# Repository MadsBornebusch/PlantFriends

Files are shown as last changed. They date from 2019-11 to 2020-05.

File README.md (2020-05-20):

<div align="center">
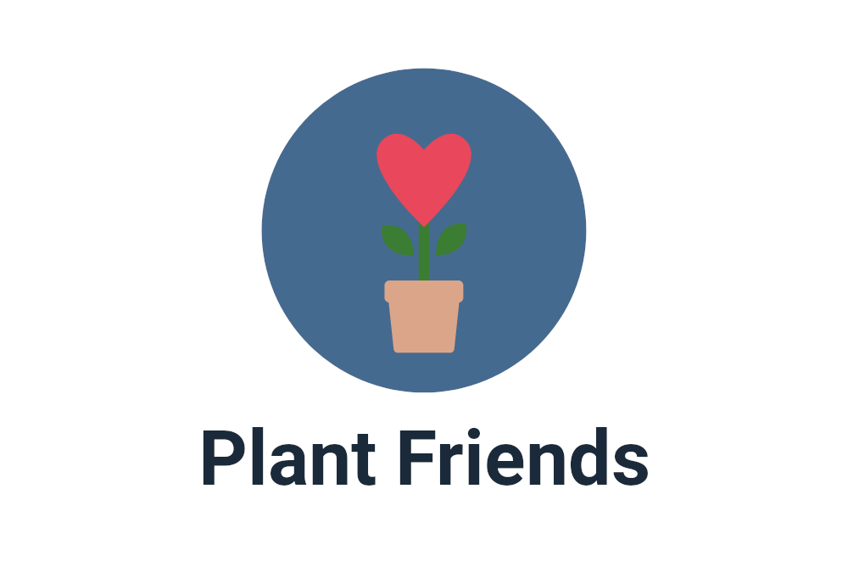
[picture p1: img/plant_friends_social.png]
  
</div>

The code is licensed under the GNU General Public License Version 3.

The PCB is licensed under the Creative Commons Attribution-ShareAlike 4.0 license due to using an [ESP8266 kicad library](https://github.com/jdunmire/kicad-ESP8266) and a particular [soil moisture probe design](https://github.com/acolomitchi/cap-soil-moisture-v2).
_________



This is a plant watering ESP8266.

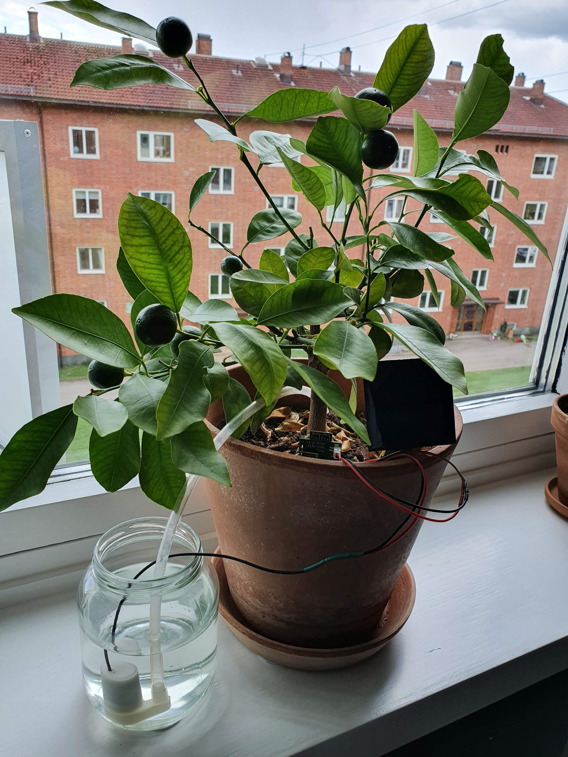
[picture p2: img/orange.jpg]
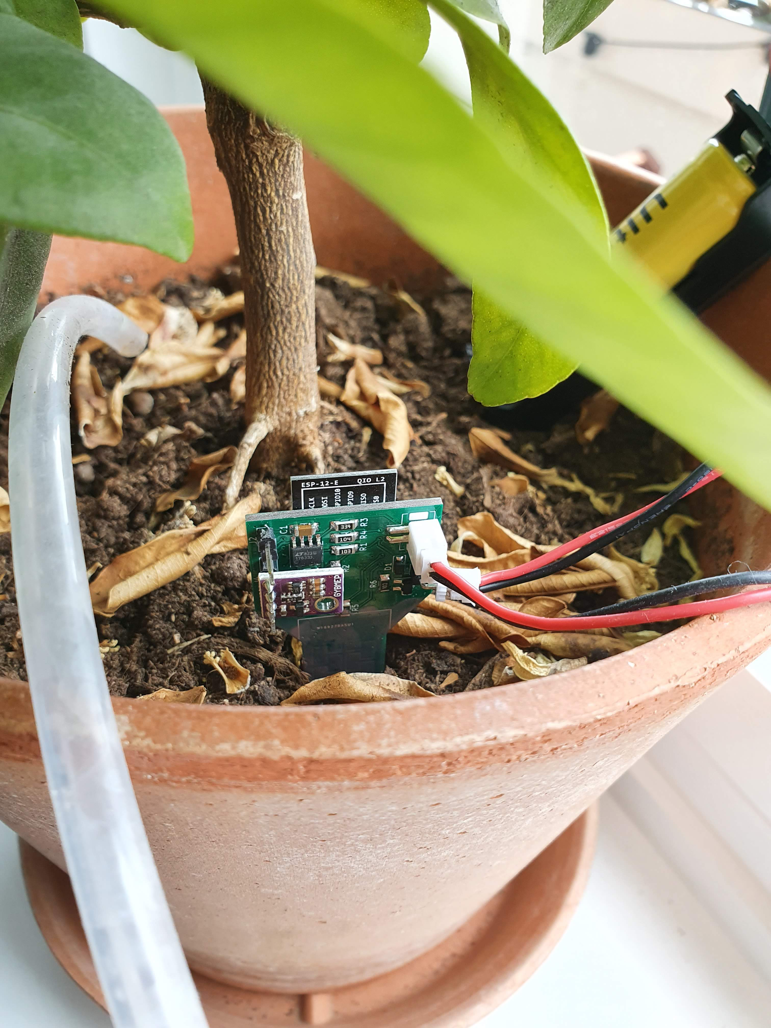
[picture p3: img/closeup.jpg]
 

# Features

* Fully open source (software and hardware)
* Automatic OTA update via Github release - enable/disable using checkbox
* OTA updates via a web interface
* Works with any MQTT server
* Works with Home Assistant discovery
* Set the sleep time, watering delay, water threshold, water time etc via MQTT
* Works with ThingSpeak
* Temperature, pressure and humidity using BME280

# PCB

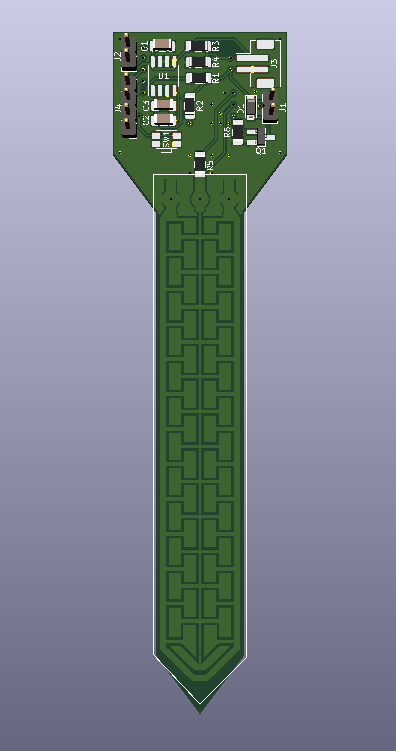
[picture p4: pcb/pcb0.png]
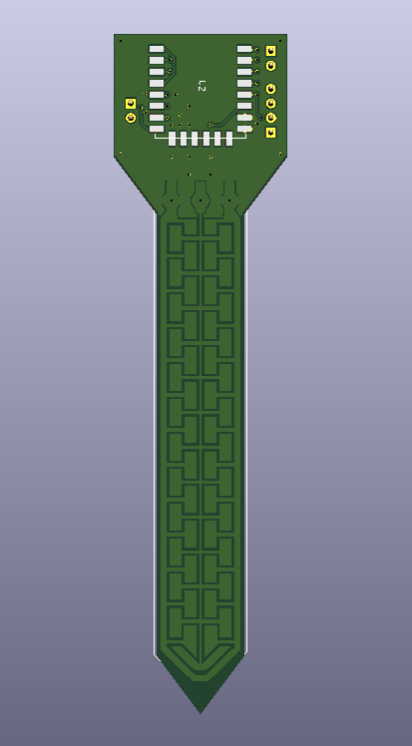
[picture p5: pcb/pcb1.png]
 

## Pinout when seen from component side:

Left side from top:

- FTDI_RX
- FTDI_TX
- SDA
- SCL
- GND
- Battery VCC

## Right side from top:

- Battery VCC IN
- GND
- VCC (3.3 V)
- Watering OUT

# Enclosure

A enclosure meant for 3D printing can be found in the [enclosure](enclosure) directory. Two variant are available. One with a closed top and one with a cutout for mounting a breakout board.

TODO: Add pictures

# Settings

The WiFi, ThingSpeak and MQTT settings can be configured via a web interface:

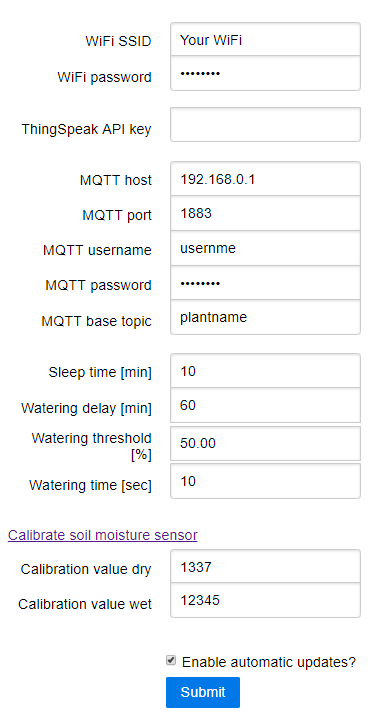
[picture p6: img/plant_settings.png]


If you do not want to use ThingSpeak simply leave the `ThingSpeak API key` field empty. Similarly the MQTT can be disabled by leaving the `MQTT base topic` empty.

At first boot the module will turn on a hotspot with the SSID: `PlantFriends` and password: `plantsarecool`.

After logging on to the WiFI simply navigate to <http://plantfriends.local> or <http://192.168.4.1> to configure the module.

The device can be put back into hotspot mode by shorting the TX and RX pins and restarting the module.

A new firmware and file system image can be uploaded by navigation to <http://plantfriends.local/update> or <http://192.168.4.1/update>.

## Calibrating the soil moisture sensor
Click "Calibrate Soil moisture sensor".
Follow the instructions. Some handy tips:
- Don't get the electronics wet, only the sensor part
- When doing the wet calibration, use a half full glass of water (or half empty if you are that tye of person). Half of the sensor should be in water. Otherwise the readings when the sensor is put in soil will be very low.
- If you need to redo a step in the calibration, just refresh the page.

Images of the wet and dry calibration are shown below:

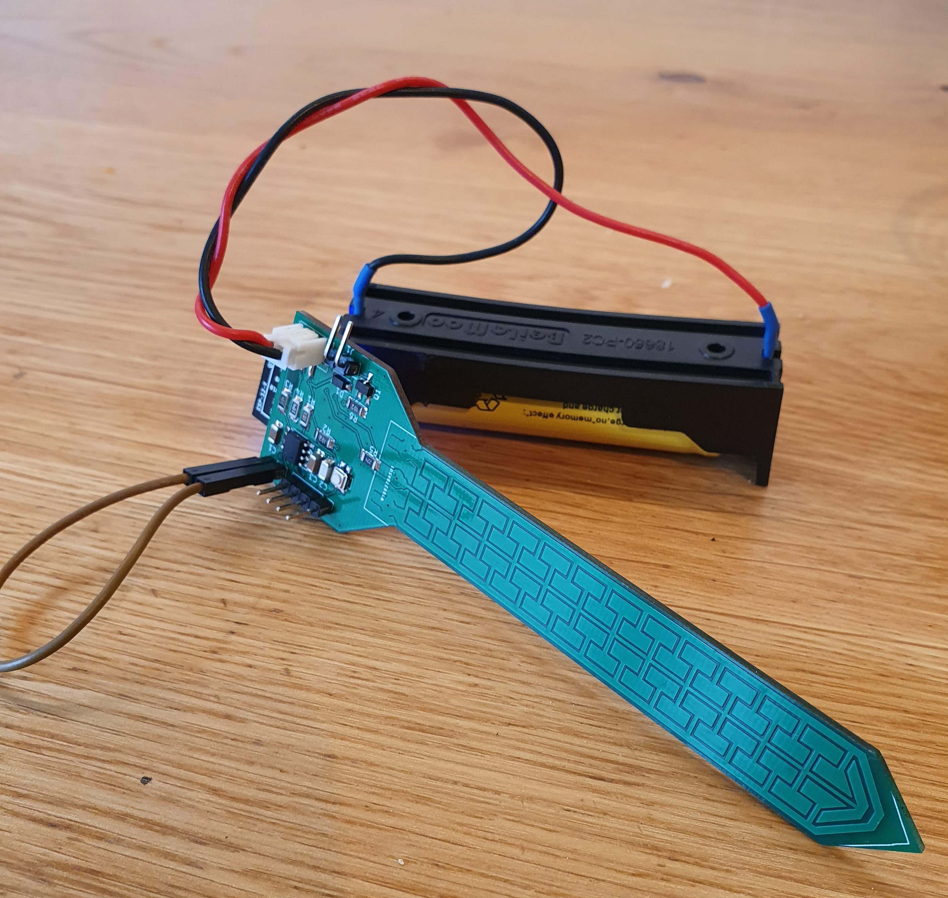
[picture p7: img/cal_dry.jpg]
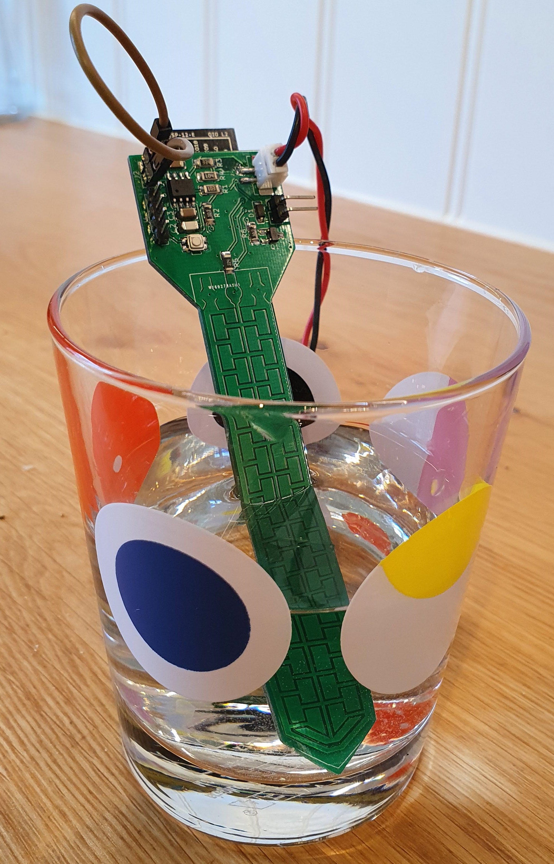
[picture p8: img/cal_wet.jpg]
 

# [Home Assistant](https://www.home-assistant.io/)

Simply activate [MQTT discovery](https://www.home-assistant.io/docs/mqtt/discovery/) by adding the following to your `configuration.yaml` file:

```yaml
mqtt:
  discovery: true
```

Assuming your plant is named `office` it will now show up as a sensor like so:

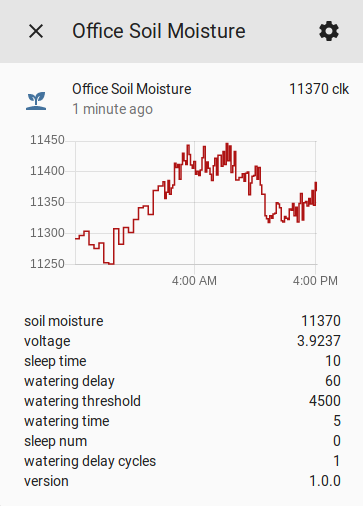
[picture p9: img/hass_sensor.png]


TODO: Upate this image!

The name of the plant is taken from the `MQTT base topic` and get be chaned via the [HTTP settings](#Settings) page.

## Advanced Home Assistant configuration

This section will guide you through on how to set the `sleep time`, `watering delay`, `watering threshold` and `watering time` directly via the Home Assitant overview page.

First add the following to your `configuration.yaml` file:

```yaml
input_number:
  office_sleep_time:
    name: Sleep Time
    min: 10
    max: 60
    step: 5
    icon: mdi:sleep
    unit_of_measurement: min
  office_watering_delay:
    name: Watering Delay
    min: 0
    max: 360
    step: 10
    icon: mdi:timer-sand
    unit_of_measurement: min
  office_watering_threshold_pct:
    name: Watering Threshold Pct
    min: 0
    max: 100
    step: 0.1
    icon: mdi:target
    unit_of_measurement: pct
  office_watering_time:
    name: Watering Time
    min: 1
    max: 30
    step: 1
    icon: mdi:water-pump
    unit_of_measurement: s
  office_automatic_ota:
    name: Automatic OTA
    min: 0
    max: 1
    step: 1
    icon: mdi:cellphone-arrow-down
```

This will create four [sliders](https://www.home-assistant.io/integrations/input_number/), one for each parameter. Remember to replace `office` with the `MQTT base topic` you have set via the web interface.

Now add the following to your `automations.yaml` file:

```yaml
- alias: Plant set slider
  trigger:
  - platform: mqtt
    topic: 'plant/+/config'
  action:
  - service: input_number.set_value
    data_template:
      entity_id: input_number.{{ trigger.topic.split('/')[1] }}_sleep_time
      value: "{{ trigger.payload_json.sleep_time | float }}"
  - service: input_number.set_value
    data_template:
      entity_id: input_number.{{ trigger.topic.split('/')[1] }}_watering_delay
      value: "{{ trigger.payload_json.watering_delay | float }}"
  - service: input_number.set_value
    data_template:
      entity_id: input_number.{{ trigger.topic.split('/')[1] }}_watering_threshold_pct
      value: "{{ trigger.payload_json.watering_threshold_pct | float }}"
  - service: input_number.set_value
    data_template:
      entity_id: input_number.{{ trigger.topic.split('/')[1] }}_watering_time
      value: "{{ trigger.payload_json.watering_time | float }}"
  - service: input_number.set_value
    data_template:
      entity_id: input_number.{{ trigger.topic.split('/')[1] }}_automatic_ota
      value: "{{ trigger.payload_json.automatic_ota | float }}"

- alias: Plant slider moved
  trigger:
  - platform: state
    entity_id:
      - input_number.office_sleep_time
      - input_number.office_watering_delay
      - input_number.office_watering_threshold_pct
      - input_number.office_watering_time
      - input_number.office_automatic_ota
  action:
  - service: mqtt.publish
    data_template:
      # The topic should always be the after the dot and before the name of the variable we want to set
      topic: "plant/{{ trigger.entity_id.split('.')[1].split('_')[:-2] | join('_') }}/config"
      retain: true
      payload: >
        {% set topic = trigger.entity_id.split('.')[1].split('_')[:-2] | join('_') %}
        {
          "sleep_time": {{ states('input_number.' + topic + '_sleep_time') | int }},
          "watering_delay": {{ states('input_number.' + topic + '_watering_delay') | int }},
          "watering_threshold": {{ states('input_number.' + topic + '_watering_threshold_pct') | int }},
          "watering_time": {{ states('input_number.' + topic + '_watering_time') | int }},
          "automatic_ota": {{ ((states('input_number.' + topic + '_automatic_ota') | int) > 0) | tojson }}
        }
```

This makes sure that the MQTT config topic is updated when the slider is moved and that the slider is always set to the MQTT config topic when it changes.

Finally you can add the sensors and the inputs slider into on group by adding the following to `groups.yaml`:

```yaml
office_plant:
    name: "Office Plant"
    icon: mdi:sprout
    entities:
    - sensor.office_soil_moisture_pct
    - sensor.office_voltage
    - sensor.office_battery
    - sensor.office_temperature
    - sensor.office_pressure
    - sensor.office_humidity
    - input_number.office_sleep_time
    - input_number.office_watering_delay
    - input_number.office_watering_threshold_pct
    - input_number.office_watering_time
    - input_number.office_automatic_ota
```

Note that the `temperature`, `pressure` and `humidity` sensors are only available if a BME280 is connected.

The plant will now show up in the Home Assistant overview like so:

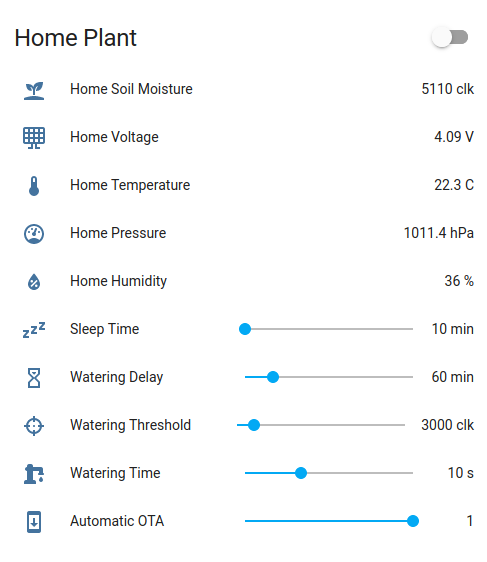
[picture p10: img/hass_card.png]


TODO: Update this image

# ThingSpeak

TODO: Add guide

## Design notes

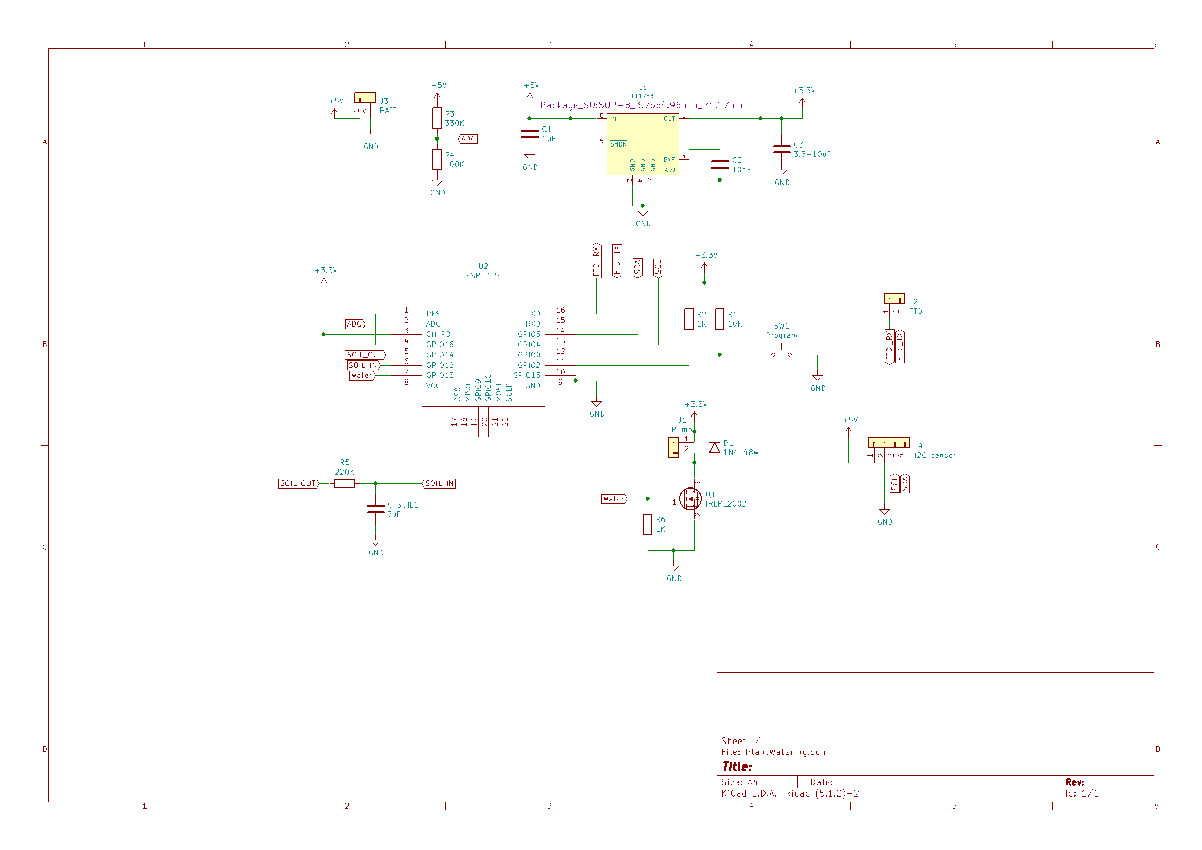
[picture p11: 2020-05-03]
pcb/schematic.png

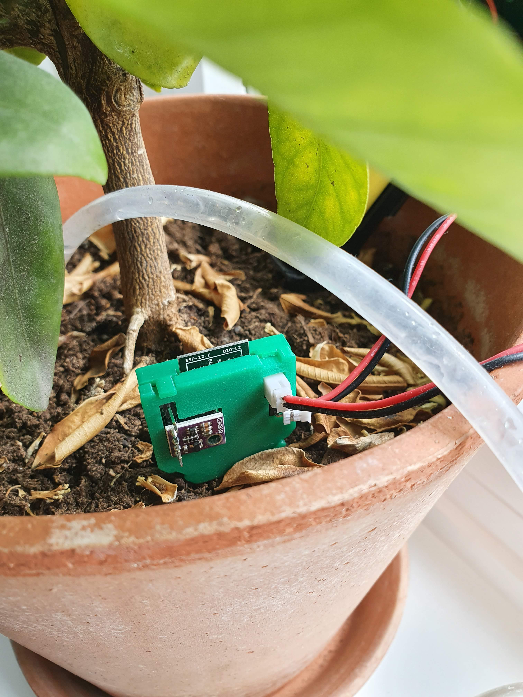
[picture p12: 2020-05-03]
img/enclosure.jpg

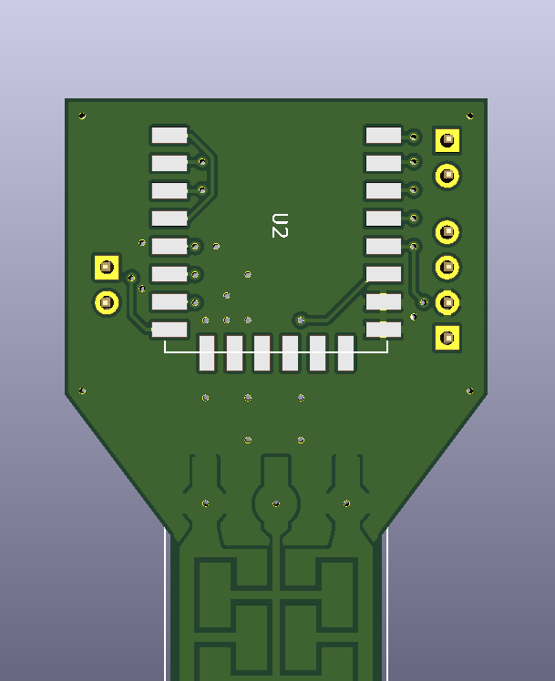
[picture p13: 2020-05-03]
pcb/pcb3.png

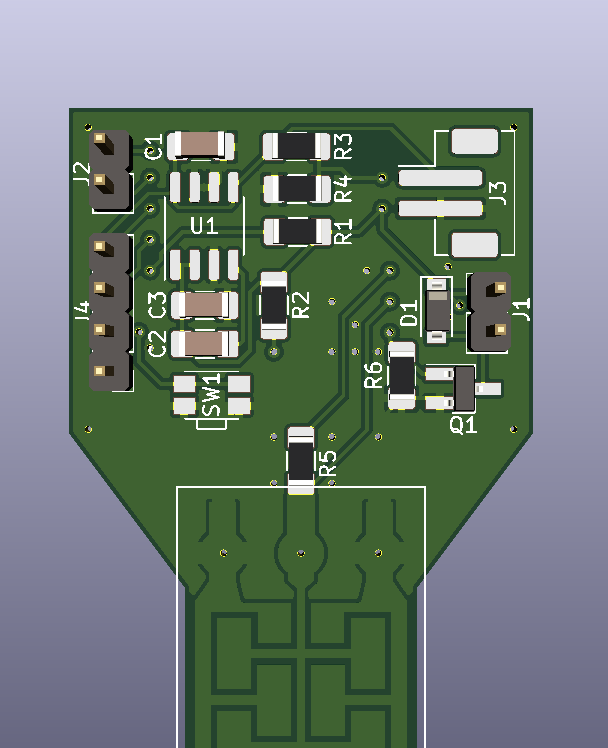
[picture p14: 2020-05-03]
pcb/pcb2.png

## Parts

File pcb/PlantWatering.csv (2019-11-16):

Id | Designator | Package | Quantity | Designation | Supplier and ref
1 | SFC | sqcap-flat | 1 | sfc*
2 | J3 | JST_PH_B2B-PH-SM4-TB_1x02-1MP_P2.00mm_Vertical | 1 | BATT
3 | U2 | ESP-12E_SMD | 1 | ESP-12E
4 | Q1 | SOT-23_Handsoldering | 1 | IRLML2502
5 | J4 | PinHeader_1x04_P2.54mm_Vertical | 1 | I2C_sensor
6 | R5 | R_1206_3216Metric_Pad1.42x1.75mm_HandSolder | 1 | 220K
7 | R2,R6 | R_1206_3216Metric_Pad1.42x1.75mm_HandSolder | 2 | 1K
8 | R1 | R_1206_3216Metric_Pad1.42x1.75mm_HandSolder | 1 | 10K
9 | C2 | C_1206_3216Metric_Pad1.42x1.75mm_HandSolder | 1 | 10nF
10 | C3 | C_1206_3216Metric_Pad1.42x1.75mm_HandSolder | 1 | 3.3-10uF
11 | J1 | PinHeader_1x02_P2.54mm_Vertical | 1 | Pump
12 | R3 | R_1206_3216Metric_Pad1.42x1.75mm_HandSolder | 1 | 330K
13 | C1 | C_1206_3216Metric_Pad1.42x1.75mm_HandSolder | 1 | 1uF
14 | D1 | D_SOD-123 | 1 | 1N4148W
15 | J2 | PinHeader_1x02_P2.54mm_Vertical | 1 | FTDI
16 | R4 | R_1206_3216Metric_Pad1.42x1.75mm_HandSolder | 1 | 100K
17 | U1 | SOP-8_3.76x4.96mm_P1.27mm | 1 | LT1763
18 | SW1 | SW_SPST_EVQP7A | 1 | Program

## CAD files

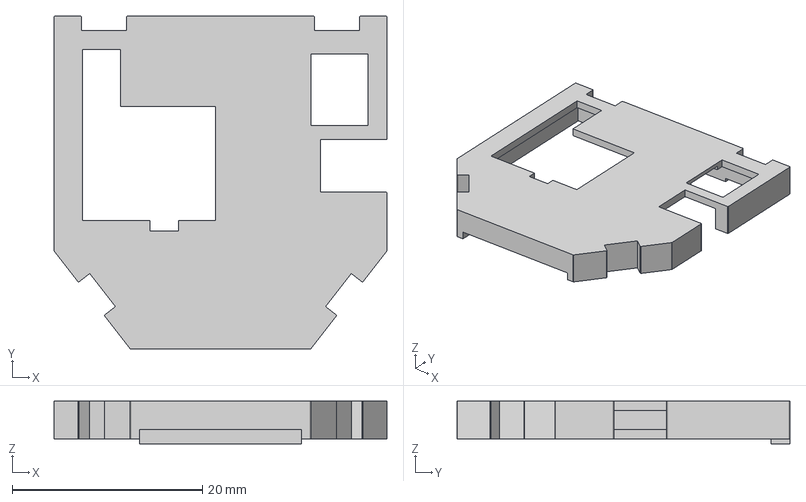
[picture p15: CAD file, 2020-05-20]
enclosure/Plant_Friends_Enclosure_top.step
35.0 x 35.0 x 4.50 mm

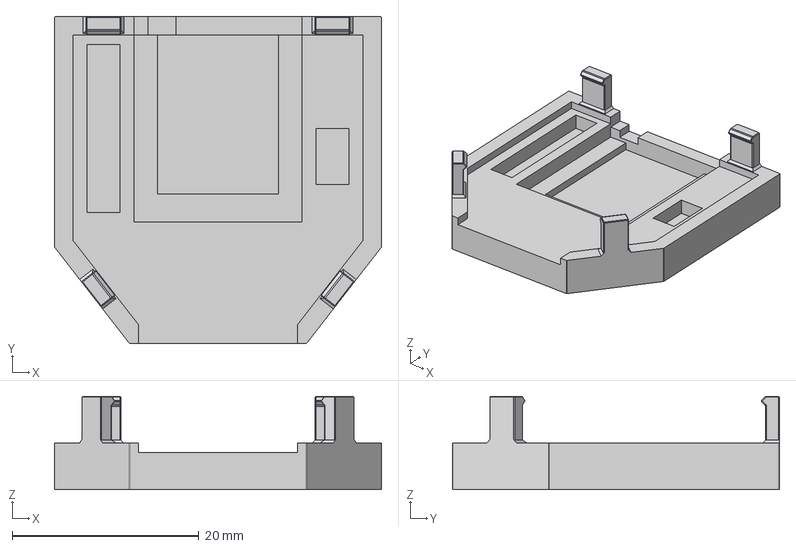
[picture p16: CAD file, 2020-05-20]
enclosure/Plant_Friends_Enclosure_bottom.step
35.0 x 35.0 x 10.0 mm

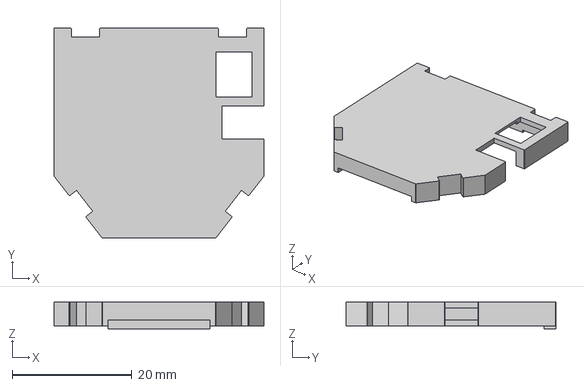
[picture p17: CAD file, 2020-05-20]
enclosure/Plant_Friends_Enclosure_top_closed.step
35.0 x 35.0 x 4.50 mm

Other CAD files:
enclosure/Plant_Friends_Enclosure_bottom.stl
enclosure/Plant_Friends_Enclosure_top.stl
enclosure/Plant_Friends_Enclosure_top_closed.stl

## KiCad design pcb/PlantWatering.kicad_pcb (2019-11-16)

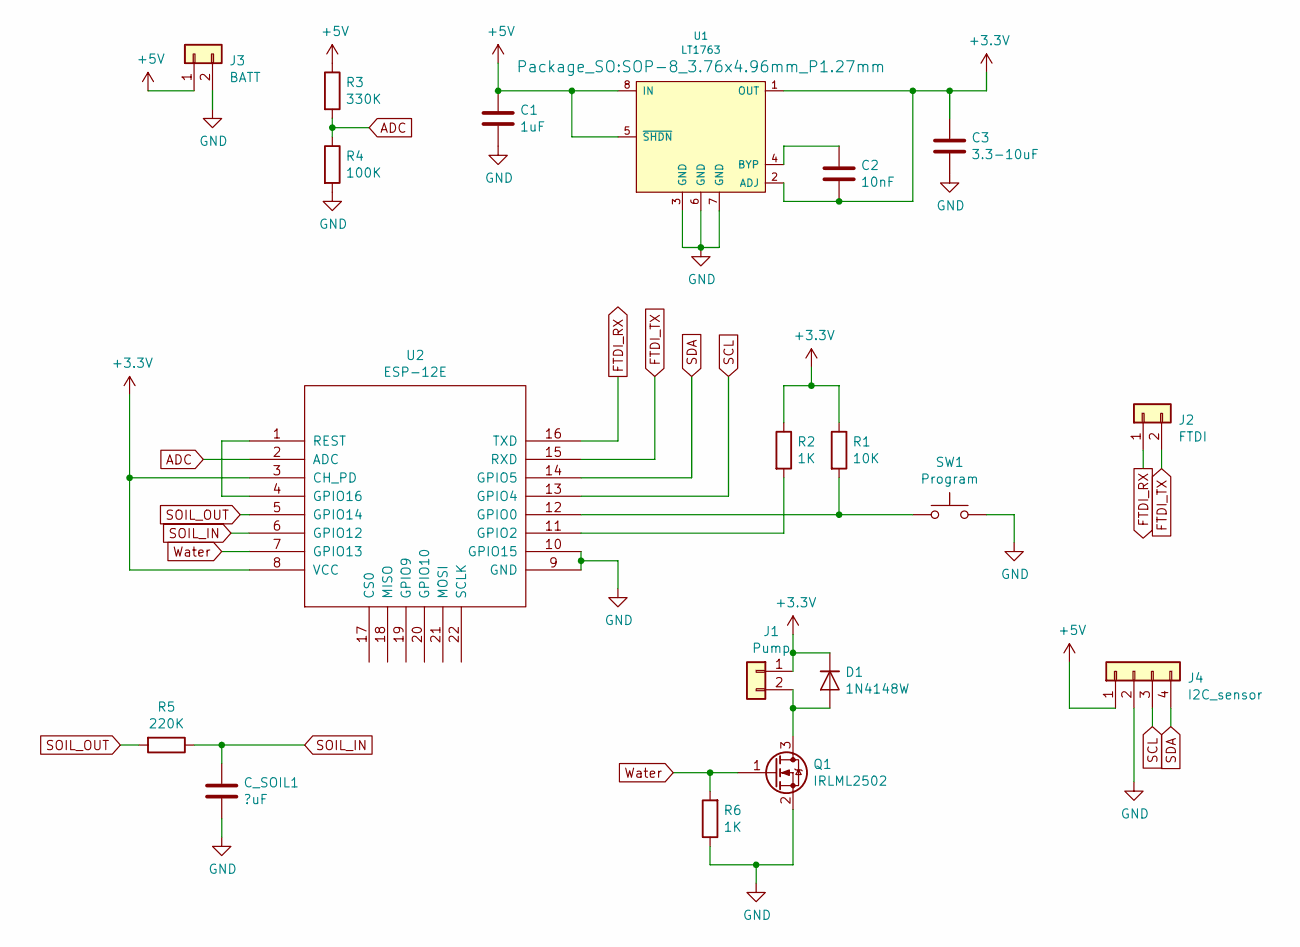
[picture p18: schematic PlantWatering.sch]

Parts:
C1: 1uF; C_1206_3216Metric_Pad1.42x1.75mm_HandSolder
C2: 10nF; C_1206_3216Metric_Pad1.42x1.75mm_HandSolder
C3: 3.3-10uF; C_1206_3216Metric_Pad1.42x1.75mm_HandSolder
C_SOIL1: ?uF; C_1206_3216Metric_Pad1.42x1.75mm_HandSolder
D1: 1N4148W; D_SOD-123
J1: Pump; PinHeader_1x02_P2.54mm_Vertical
J2: FTDI; PinHeader_1x02_P2.54mm_Vertical
J3: BATT; JST_PH_B2B-PH-SM4-TB_1x02-1MP_P2.00mm_Vertical
J4: I2C_sensor; PinHeader_1x04_P2.54mm_Vertical
Q1: IRLML2502; SOT-23_Handsoldering
R1: 10K; R_1206_3216Metric_Pad1.42x1.75mm_HandSolder
R2, R6: 1K; R_1206_3216Metric_Pad1.42x1.75mm_HandSolder
R3: 330K; R_1206_3216Metric_Pad1.42x1.75mm_HandSolder
R4: 100K; R_1206_3216Metric_Pad1.42x1.75mm_HandSolder
R5: 220K; R_1206_3216Metric_Pad1.42x1.75mm_HandSolder
SW1: Program; SW_SPST_EVQP7A
U1: LT1763; SOP-8_3.76x4.96mm_P1.27mm
U2: ESP-12E; ESP-12E_SMD

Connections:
+3V3: C2.2, C3.1, D1.1 (K), J1.1, R1.1, R2.1, U1.1 (OUT), U1.2 (ADJ), U2.3 (CH_PD), U2.8 (VCC)
+5V: C1.1, J3.1, J4.1, R3.1, U1.5 (~SHDN), U1.8 (IN)
ADC: R3.2, R4.1, U2.2 (ADC)
FTDI_RX: J2.1, U2.16 (TXD)
FTDI_TX: J2.2, U2.15 (RXD)
GND: C1.2, C3.2, C_SOIL1.2, J3.2, J4.2, Q1.2 (S), R4.2, R6.1, SW1.2, U1.3 (GND), U1.6 (GND), U1.7 (GND), U2.9 (GND), U2.10 (GPIO15)
unnamed: C2.1, U1.4 (BYP)
unnamed: D1.2 (A), J1.2, Q1.3 (D)
unnamed: R1.2, SW1.1, U2.12 (GPIO0)
unnamed: R2.2, U2.11 (GPIO2)
unnamed: U2.1 (REST), U2.4 (GPIO16)
SCL: J4.3, U2.13 (GPIO4)
SDA: J4.4, U2.14 (GPIO5)
SOIL_IN: C_SOIL1.1, R5.1, U2.6 (GPIO12)
SOIL_OUT: R5.2, U2.5 (GPIO14)
Water: Q1.1 (G), R6.2, U2.7 (GPIO13)

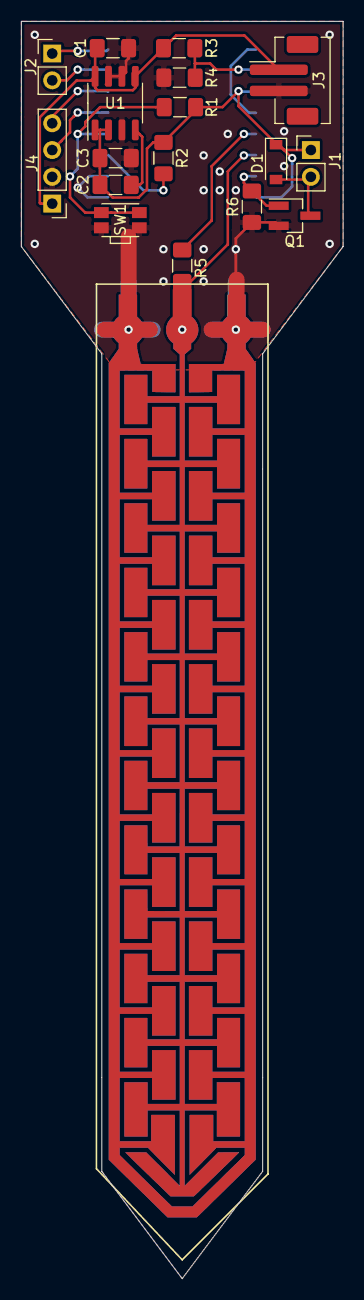
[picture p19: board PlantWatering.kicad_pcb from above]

Board: 2 copper layers, 30.5 x 119.1 mm, 19 parts (1 on the bottom side), 16 nets.

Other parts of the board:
SFC: sfc*; sqcap-flat

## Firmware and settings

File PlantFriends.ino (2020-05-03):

#include <Adafruit_BME280.h>
#include <ArduinoJson.h>
#include <AsyncMqttClient.h>
#include <ESPAsyncWebServer.h>
#include <EEPROM.h>
#include <ESP8266httpUpdate.h>
#include <ESP8266mDNS.h>
#include <ESP8266WiFi.h>
#include "WiFiClientSecure.h"

#include "AsyncElegantOtaSpiffs.h"
#include "secret.h"

#define SW_VERSION "1.1.0"

// Define the access point SSID and password
#define WIFI_AP_SSID "PlantFriends"
#define WIFI_AP_PASSWORD "plantsarecool"

// Default sleep time in minutes
// Note that this can never be lower than "SLEEP_INTERVAL"
#define DEFAULT_SLEEP_TIME (10U)

// Default minimum time between watering plant (minutes) and watering delay
#define DEFAULT_WATERING_DELAY (60U)

// Default watering threshold in percent
#define DEFAULT_WATERING_THRESHOLD_PCT (16.0)

// Default watering time in seconds
#define DEFAULT_WATERING_TIME (3U)

// Define number of soil measurements
#define N_SOIL_MEAS (4U)

// Define default calibration value for dry measurement
#define DEFAULT_CALIBRATION_DRY (0U)

// Define default calibration value for wet measurement
#define DEFAULT_CALIBRATION_WET (20000U)

// Sleep interval can safely be set from 1 to 30 minutes (possibly higher, but there is a limitation to sleep time with the esp8266). Should be smaller or equal to SLEEP_TIME
#define SLEEP_INTERVAL (10U)

// Calculate sleep interval and number of sleeps
#define SLEEP_INTERVAL_US (SLEEP_INTERVAL * 60UL * 1000000UL)

// RTC memory address to use for sleep counter - note that the first 128 bytes are used by the OTA and the offset is set in block of 4 bytes, so we set the value to 128/4=32, so OTA still works
#define SLEEP_DATA_ADDR (32U)

// Define whether to post to Thingspeak
#define POST_TO_THINGSPEAK

// Define soil output and measurement pins
#define SOIL_OUT (14U)
#define SOIL_IN (12U)

// Define watering pin
#define WATERING_OUT (13U)

// Define LED pin for built in LED (ESP-12 board)
#define LED_PIN (2U)

// UART pins - if these are shorted at boot, then it will turn on the access point
#define TX_PIN (1U)
#define RX_PIN (3U)

// This is used to determine if the EEPROM and RTC memory has been configured
static const uint64_t MAGIC_NUMBER = 0x3b04cd9e94521f9a;

typedef struct {
  // Can be set via the web interface
  uint64_t magic_number; // Used to determine if the EEPROM have been configured or not
  char wifi_ssid[33]; // SSID should be a maximum of 32 characters according to the specs
  char wifi_password[33]; // Restrict password length to 32 characters
  char thingspeak_api_key[17]; // The API is 16 characters
  char mqtt_host[51]; // Restrict URLs to 50 characters
  uint16_t mqtt_port;
  char mqtt_username[33]; // Just set these to 32 as well
  char mqtt_password[33];
  char mqtt_base_topic[33];
  uint32_t cal_dry;
  uint32_t cal_wet;

  // Can be set via MQTT and the web interface
  uint8_t sleep_time;
  uint16_t watering_delay;
  float watering_threshold_pct;
  uint8_t watering_time;
  bool automatic_ota; // Flag used to enable automatic OTA
  bool override_retained_config_topic; // Used to override the retained config topic, so the values set via the web interface does not get overriden
} eeprom_config_t;

typedef struct {
  uint64_t magic_number; // Used to determine if the RTC memory has been configured or not
  uint8_t sleep_num; // Stores the current sleep interval number
  uint8_t watering_delay_cycles; // Stores the number of cycles the board must sleep before it will water the plant again
  uint16_t firmware_update_counter; // Used to only check for updates every 24 hrs
} __attribute__ ((packed, aligned(4))) sleep_data_t; // The struct needs to be 4-byte aligned in the RTC memory

// Wifi
WiFiClientSecure client;
//#define WIFI_SSID "YourWifiSSID" // Defined in secret.h
//#define WIFI_PASSWORD "YourWifiPassword" // Defined in secret.h

// MQTT
AsyncMqttClient mqttClient;
//#define MQTT_HOST "192.168.1.10" // Defined in secret.h
//#define MQTT_PORT 1883 // Defined in secret.h
//#define MQTT_USERNAME "" // Defined in secret.h
//#define MQTT_PASSWORD "" // Defined in secret.h
//#define MQTT_BASE_TOPIC "" // Defined in secret.h

// ThingSpeak variables
//#define THINGSPEAK_API_KEY "YourWriteApiKey" // Defined in secret.h
const char* thingspeak_server = "api.thingspeak.com";
const char* thingspeak_resource = "/update?api_key=";

// Used for the AP (Access Point) - will be turned on at first boot
static AsyncWebServer httpServer(80);

// Used for updating the firmware and file system via HTTP
static AsyncElegantOtaSpiffs elegantUpdater(LED_PIN, LOW);

// Flag and timer used for measuring the time it takes for the voltage to rise over the capacitive sensor
static volatile bool soil_timer_flag;
static volatile uint32_t soil_timer;

// Used to check if a MQTT package was succesfully sent
static volatile uint16 publishedPacketId = -1;

// BME280 sensor
Adafruit_BME280 bme280; // Connect to the BME280 via I2C


static void bubbleSort(uint32_t *array, size_t n) {
  // This sorting algorithm is shamelessly copied from https://en.wikipedia.org/wiki/Bubble_sort
  while (n > 1) {
    size_t new_n = 0;
    for (size_t i = 1; i < n; i++) {
      if (array[i - 1] > array[i]) {
        // Swap places in array
        uint32_t temp = array[i];
        array[i] = array[i - 1];
        array[i - 1] = temp;
        new_n = i;
      }
    }
    n = new_n;
  }
}

static uint32_t getMedian(uint32_t *array, size_t n) {
  // Sort array
  bubbleSort(array, n);

  // Check last bit to see if number is even or uneven
  if (n & 0x01) {
    // Number is uneven
    return array[n / 2];
  } else {
    // Number is even
    return (array[n / 2 - 1] + array[n / 2]) / 2;
  }
}

static long getMean(uint32_t *array, size_t n) {
  long sum = 0;
  for (size_t i = 0; i < n; i++)
    sum += array[i];
  return sum / n;
}

static void handleLongSleep(sleep_data_t *sleep_data) {
  if (sizeof(sleep_data_t) % 4 != 0) {
    Serial.println(F("Sleep data is NOT 4 byte aligned! Rebooting..."));
    delay(5000);
    ESP.restart();
  }

  if (!ESP.rtcUserMemoryRead(SLEEP_DATA_ADDR, (uint32_t*)sleep_data, sizeof(sleep_data_t)))
    Serial.println(F("Failed to read RTC user memory"));

  if (sleep_data->magic_number != MAGIC_NUMBER) {
    Serial.println(F("Failed to read sleep data from the RTC memory"));
    sleep_data->magic_number = MAGIC_NUMBER;
    sleep_data->sleep_num = 1;
    sleep_data->watering_delay_cycles = 1;
    sleep_data->firmware_update_counter = 0;
  } else {
    // We just woke up, so increment the counter
    sleep_data->firmware_update_counter++;
  }

  Serial.print(F("Sleep number: ")); Serial.print(sleep_data->sleep_num);
  Serial.print(F(", watering delay cycles: ")); Serial.print(sleep_data->watering_delay_cycles);
  Serial.print(F(", firmware update counter: ")); Serial.println(sleep_data->firmware_update_counter);

  // Check if we should go back to sleep immediately
  if (--sleep_data->sleep_num != 0) {
    Serial.print(F("Going to sleep again. Times left to sleep: ")); Serial.println(sleep_data->sleep_num);
    if (!ESP.rtcUserMemoryWrite(SLEEP_DATA_ADDR, (uint32_t*)sleep_data, sizeof(sleep_data_t)))
      Serial.println(F("Failed to write RTC user memory"));
    ESP.deepSleep(SLEEP_INTERVAL_US, WAKE_RF_DEFAULT);
  }
}

static void longSleep(const eeprom_config_t *eeprom_config, sleep_data_t *sleep_data) {
  Serial.print(F("Going into deep sleep for ")); Serial.print(eeprom_config->sleep_time); Serial.println(F(" min"));
  if (sizeof(sleep_data_t) % 4 != 0) {
    Serial.println(F("Sleep data is NOT 4 byte aligned! Rebooting..."));
    delay(5000);
    ESP.restart();
  }

  sleep_data->magic_number = MAGIC_NUMBER;
  sleep_data->sleep_num = eeprom_config->sleep_time / SLEEP_INTERVAL; // Set the number of times it should wakeup and go back to sleep again immediately
  Serial.print(F("Number of sleeps left: ")); Serial.println(sleep_data->sleep_num);
  if (!ESP.rtcUserMemoryWrite(SLEEP_DATA_ADDR, (uint32_t*)sleep_data, sizeof(sleep_data_t)))
    Serial.println(F("Failed to write RTC user memory"));
  ESP.deepSleep(SLEEP_INTERVAL_US, WAKE_RF_DEFAULT);
}

// Copy of ESP.getCycleCount(), but can safely be called inside an interrupt
static inline ICACHE_RAM_ATTR uint32_t GetCycleCountIRQ() {
  uint32_t ccount;
  __asm__ __volatile__("esync; rsr %0,ccount":"=a" (ccount));
  return ccount;
}

static void ICACHE_RAM_ATTR soilInterrupt() {
  soil_timer = GetCycleCountIRQ();
  soil_timer_flag = true;
}

static bool readSoil(uint32_t *soil_measurements, size_t n_meas) {
  pinMode(SOIL_OUT, OUTPUT);

  bool result = true;
  for (size_t i = 0; i < n_meas; i++) {
    Serial.print(i); Serial.print(": ");
    // Discharge the capacitor by setting both pins low
    digitalWrite(SOIL_OUT, LOW);
    pinMode(SOIL_IN, OUTPUT);
    digitalWrite(SOIL_IN, LOW);
    // The ESP8266 can sink 12 mA max, at 4.2 V and assuming the capacitor is 1 uF (which is very high) the time constant is 350 us
    // The capacitor should be discharged after 5 time constants so 10 ms should be plenty
    // Check out: http://www.learningaboutelectronics.com/Articles/How-long-does-it-take-to-discharge-a-capacitor for more information
    delay(10);
    pinMode(SOIL_IN, INPUT); // Change the capacitor measurement pin to input again
    attachInterrupt(digitalPinToInterrupt(SOIL_IN), soilInterrupt, RISING);
    soil_timer_flag = false; // Reset the flag used for telling when the interrupt has triggered
    uint32_t timer_start = ESP.getCycleCount(); // Get the current cycle count
    digitalWrite(SOIL_OUT, HIGH); // Now set the pin high and measure the rise time using the "SOIL_IN" pin interrupt
    int timeout = 1 * 100; // 1 second(s) timeout
    while (!soil_timer_flag && (timeout-- > 0))
      delay(10); // Wait for interrupt to have been called or a timeout
    detachInterrupt(digitalPinToInterrupt(SOIL_IN));
    if (timeout == 0) {  // It took more than x seconds for the voltage to rise
      result = false;
      break;
    } else {
      soil_measurements[i] = soil_timer - timer_start; // Calculate the soil measurement using the soil_timer set in the interrupt
      Serial.println(soil_measurements[i]); // Print the measurement
    }
  }

  pinMode(SOIL_OUT, INPUT); // Save power
  return result;
}

uint32_t readSoilMean(uint8_t n_meas) {
  uint32_t soil_measurements[n_meas];
  if (!readSoil(soil_measurements, sizeof(soil_measurements) / sizeof(soil_measurements[0]))) {
    Serial.println(F("Timeout reading the soil measurement! Rebooting..."));
    delay(5000);
    ESP.restart();
  }
  return getMean(soil_measurements, sizeof(soil_measurements) / sizeof(soil_measurements[0]));
}

uint32_t readSoilMedian(uint8_t n_meas) {
  uint32_t soil_measurements[n_meas];
  if (!readSoil(soil_measurements, sizeof(soil_measurements) / sizeof(soil_measurements[0]))) {
    Serial.println(F("Timeout reading the soil measurement! Rebooting..."));
    delay(5000);
    ESP.restart();
  }
  return getMedian(soil_measurements, sizeof(soil_measurements) / sizeof(soil_measurements[0]));
}

static void blinkLED() {
  pinMode(LED_PIN, OUTPUT);
  digitalWrite(LED_PIN, LOW);
  delay(50);
  pinMode(LED_PIN, INPUT); // Save power
}

static void onMqttPublish(uint16_t packetId) {
  publishedPacketId = packetId;
  //Serial.printf("Publish acknowledged - packet ID: %u\n", packetId);
}

static bool mqttPublishBlocking(String topic, const char *buffer, size_t length, bool retain, int timeout) {
  publishedPacketId = -1;
  uint16_t packetId = mqttClient.publish(topic.c_str(), 2, retain, buffer, length);
  while (publishedPacketId != packetId && (timeout-- > 0))
    delay(100);
  return timeout > 0;
}

static void startAsyncHotspot(bool *p_run_hotspot, eeprom_config_t *eeprom_config) {
  // Sensor calibration values:
  uint32_t cal_meas_dry = eeprom_config->magic_number == MAGIC_NUMBER ? eeprom_config->cal_dry : DEFAULT_CALIBRATION_DRY;
  uint32_t cal_meas_wet = eeprom_config->magic_number == MAGIC_NUMBER ? eeprom_config->cal_wet : DEFAULT_CALIBRATION_WET;

  // Configure the hotspot
  // Note that we set the maximum number of connection to 1
  int channel = 1, ssid_hidden = 0, max_connection = 1;
  if (!WiFi.softAP(WIFI_AP_SSID, WIFI_AP_PASSWORD, channel, ssid_hidden, max_connection)) {
    Serial.println(F("Failed to start hotspot! Rebooting..."));
    delay(5000);
    ESP.restart();
  }

  WiFi.softAPConfig(IPAddress(192, 168, 4, 1), IPAddress(192, 168, 4, 1), IPAddress(255, 255, 255, 0));
  IPAddress ip = WiFi.softAPIP();
  Serial.print(F("AP IP address: ")); Serial.println(ip);

  MDNS.begin(F("plantfriends"));
  MDNS.addService(F("http"), F("tcp"), 80);
  Serial.println(F("Hostname: http://plantfriends.local"));

  if (!SPIFFS.begin()) {
    Serial.println(F("An Error has occurred while mounting SPIFFS! Rebooting..."));
    delay(5000);
    ESP.restart();
  }

  elegantUpdater.begin(&httpServer); // Start ElegantOTA

  // Add routes for the different files and pages
  httpServer.on("/pure-min.css", HTTP_GET, [](AsyncWebServerRequest *request) {
    // Use Pure to style the from: https://purecss.io/forms/
    request->send(SPIFFS, F("/pure-min.css"), F("text/css"));
  });
  httpServer.on("/style.css", HTTP_GET, [](AsyncWebServerRequest *request) {
    // Som additional css to make it look a little nicer
    request->send(SPIFFS, F("/style.css"), F("text/css"));
  });

  // This is the main page with the form for configuring the device
  httpServer.on("/", HTTP_GET, [&eeprom_config, &p_run_hotspot, &cal_meas_dry, &cal_meas_wet](AsyncWebServerRequest *request) {
    auto processor = [&eeprom_config, &cal_meas_dry, &cal_meas_wet](const String &var) {
      if (var == F("WIFI_SSID"))
        return String(eeprom_config->magic_number == MAGIC_NUMBER ? eeprom_config->wifi_ssid : WIFI_SSID);
      else if (var == F("WIFI_PASSWORD"))
        return String(eeprom_config->magic_number == MAGIC_NUMBER ? eeprom_config->wifi_password : WIFI_PASSWORD);
      else if (var == F("THINGSPEAK_API_KEY"))
        return String(eeprom_config->magic_number == MAGIC_NUMBER ? eeprom_config->thingspeak_api_key : THINGSPEAK_API_KEY);
      else if (var == F("MQTT_HOST"))
        return String(eeprom_config->magic_number == MAGIC_NUMBER ? eeprom_config->mqtt_host : MQTT_HOST);
      else if (var == F("MQTT_PORT"))
        return String(eeprom_config->magic_number == MAGIC_NUMBER ? eeprom_config->mqtt_port : MQTT_PORT);
      else if (var == F("MQTT_USERNAME"))
        return String(eeprom_config->magic_number == MAGIC_NUMBER ? eeprom_config->mqtt_username : MQTT_USERNAME);
      else if (var == F("MQTT_PASSWORD"))
        return String(eeprom_config->magic_number == MAGIC_NUMBER ? eeprom_config->mqtt_password : MQTT_PASSWORD);
      else if (var == F("MQTT_BASE_TOPIC"))
        return String(eeprom_config->magic_number == MAGIC_NUMBER ? eeprom_config->mqtt_base_topic : MQTT_BASE_TOPIC);
      else if (var == F("sleep_time"))
        return String(eeprom_config->magic_number == MAGIC_NUMBER ? eeprom_config->sleep_time : DEFAULT_SLEEP_TIME);
      else if (var == F("watering_delay"))
        return String(eeprom_config->magic_number == MAGIC_NUMBER ? eeprom_config->watering_delay : DEFAULT_WATERING_DELAY);
      else if (var == F("watering_threshold_pct"))
        return String(eeprom_config->magic_number == MAGIC_NUMBER ? eeprom_config->watering_threshold_pct : DEFAULT_WATERING_THRESHOLD_PCT);
      else if (var == F("watering_time"))
        return String(eeprom_config->magic_number == MAGIC_NUMBER ? eeprom_config->watering_time : DEFAULT_WATERING_TIME);
      else if (var == F("cal_dry"))
        return String(cal_meas_dry); // Setting the default value is handled when the variable is initialized
      else if (var == F("cal_wet"))
        return String(cal_meas_wet); // Setting the default value is handled when the variable is initialized
      else if (var == F("automatic_ota"))
        return String(eeprom_config->magic_number == MAGIC_NUMBER ? (eeprom_config->automatic_ota ? "checked" : "") : "checked");
      return String();
    };

    // Send the index as a template
    request->send(SPIFFS, F("/index.html"), F("text/html"), false, processor);
  });

  httpServer.on("/cal", HTTP_GET, [&eeprom_config, &p_run_hotspot](AsyncWebServerRequest *request) {
    request->send(SPIFFS, F("/cal.html"), F("text/html"), false, nullptr);
    return;
  });

  httpServer.on("/caldry", HTTP_GET, [&eeprom_config, &p_run_hotspot, &cal_meas_dry](AsyncWebServerRequest *request) {
    uint32_t soil_moisture = readSoilMean(N_SOIL_MEAS);
    auto processor = [&soil_moisture](const String &var) {
      if (var == F("cal_dry"))
        return String(soil_moisture);
    };
    request->send(SPIFFS, F("/caldry.html"), F("text/html"), false, processor);
    cal_meas_dry = soil_moisture;
    return;
  });

  httpServer.on("/calwet", HTTP_GET, [&eeprom_config, &p_run_hotspot, &cal_meas_wet](AsyncWebServerRequest *request) {
    uint32_t soil_moisture = readSoilMean(N_SOIL_MEAS);
    auto processor = [&soil_moisture](const String &var) {
      if (var == F("cal_wet"))
        return String(soil_moisture);
    };
    request->send(SPIFFS, F("/calwet.html"), F("text/html"), false, processor);
    cal_meas_wet = soil_moisture;
    return;
  });

  // Handle the post request
  httpServer.on("/", HTTP_POST, [&eeprom_config, &p_run_hotspot](AsyncWebServerRequest *request) {
    if (!request->hasArg(F("wifi_ssid")) || !request->hasArg(F("wifi_password"))
      || !request->hasArg(F("thingspeak_api_key"))
      || !request->hasArg(F("mqtt_host")) || !request->hasArg(F("mqtt_port"))
      || !request->hasArg(F("mqtt_username")) || !request->hasArg(F("mqtt_password")) || !request->hasArg(F("mqtt_base_topic"))
      || !request->hasArg(F("sleep_time")) || !request->hasArg(F("watering_delay"))
      || !request->hasArg(F("watering_threshold_pct")) || !request->hasArg(F("watering_time"))
      || !request->hasArg(F("cal_dry")) || !request->hasArg(F("cal_wet")) ){
      request->send(400, F("text/plain"), F("400: Invalid request"));
      return;
    }

    strncpy(eeprom_config->wifi_ssid, request->arg(F("wifi_ssid")).c_str(), sizeof(eeprom_config->wifi_ssid) - 1);
    eeprom_config->wifi_ssid[sizeof(eeprom_config->wifi_ssid) - 1] = '\0'; // Make sure the buffer is null-terminated

    strncpy(eeprom_config->wifi_password, request->arg(F("wifi_password")).c_str(), sizeof(eeprom_config->wifi_password) - 1);
    eeprom_config->wifi_password[sizeof(eeprom_config->wifi_password) - 1] = '\0'; // Make sure the buffer is null-terminated

    strncpy(eeprom_config->thingspeak_api_key, request->arg(F("thingspeak_api_key")).c_str(), sizeof(eeprom_config->thingspeak_api_key) - 1);
    eeprom_config->thingspeak_api_key[sizeof(eeprom_config->thingspeak_api_key) - 1] = '\0'; // Make sure the buffer is null-terminated

    strncpy(eeprom_config->mqtt_host, request->arg(F("mqtt_host")).c_str(), sizeof(eeprom_config->mqtt_host) - 1);
    eeprom_config->mqtt_host[sizeof(eeprom_config->mqtt_host) - 1] = '\0'; // Make sure the buffer is null-terminated

    eeprom_config->mqtt_port = request->arg(F("mqtt_port")).toInt();

    strncpy(eeprom_config->mqtt_username, request->arg(F("mqtt_username")).c_str(), sizeof(eeprom_config->mqtt_username) - 1);
    eeprom_config->mqtt_username[sizeof(eeprom_config->mqtt_username) - 1] = '\0'; // Make sure the buffer is null-terminated

    strncpy(eeprom_config->mqtt_password, request->arg(F("mqtt_password")).c_str(), sizeof(eeprom_config->mqtt_password) - 1);
    eeprom_config->mqtt_password[sizeof(eeprom_config->mqtt_password) - 1] = '\0'; // Make sure the buffer is null-terminated

    strncpy(eeprom_config->mqtt_base_topic, request->arg(F("mqtt_base_topic")).c_str(), sizeof(eeprom_config->mqtt_base_topic) - 1);
    eeprom_config->mqtt_base_topic[sizeof(eeprom_config->mqtt_base_topic) - 1] = '\0'; // Make sure the buffer is null-terminated

    decltype(eeprom_config_t::sleep_time) sleep_time = request->arg(F("sleep_time")).toInt();
    decltype(eeprom_config_t::watering_delay) watering_delay = request->arg(F("watering_delay")).toInt();
    decltype(eeprom_config_t::watering_threshold_pct) watering_threshold_pct = request->arg(F("watering_threshold_pct")).toFloat();
    decltype(eeprom_config_t::watering_time) watering_time = request->arg(F("watering_time")).toInt();
    decltype(eeprom_config_t::cal_dry) cal_dry = request->arg(F("cal_dry")).toInt();
    decltype(eeprom_config_t::cal_wet) cal_wet = request->arg(F("cal_wet")).toInt();
    decltype(eeprom_config_t::automatic_ota) automatic_ota = request->hasArg(F("automatic_ota")); // The argument is only present when the checkbox is checked

    bool changed = eeprom_config->sleep_time != sleep_time ||
      eeprom_config->watering_delay != watering_delay ||
      eeprom_config->watering_threshold_pct != watering_threshold_pct ||
      eeprom_config->watering_time != watering_time ||
      eeprom_config->cal_dry != cal_dry ||
      eeprom_config->cal_wet != cal_wet ||
      eeprom_config->automatic_ota != automatic_ota;

    // Check if the values has changed
    if (changed) {
      eeprom_config->override_retained_config_topic = true; // Make sure the config topic gets overriden on the next boot
      eeprom_config->sleep_time = sleep_time;
      eeprom_config->watering_delay = watering_delay;
      eeprom_config->watering_threshold_pct = watering_threshold_pct;
      eeprom_config->watering_time = watering_time;
      eeprom_config->cal_dry = cal_dry;
      eeprom_config->cal_wet = cal_wet;
      eeprom_config->automatic_ota = automatic_ota;
    }
    // The values where succesfully configured
    eeprom_config->magic_number = MAGIC_NUMBER;
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
void loop() {
  Serial.println(F("Somewhere we took a wrong turn and ended up in the main loop..."));
  ESP.restart();
}

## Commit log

2019-08-05 First commit, first prototype on ESP8266 soil moisture sensing
2019-08-05 Bugfix in the long deep sleep, filtering of soil moisture measurement
    [PlantWateringESP8266.ino]
2019-08-31 Implemented minimum time between watering in order to measure more often without drowning the plant. Also moved LED blink.
2019-11-16 Updated README with PCB pins
2019-11-16 Fix to use interrupts when building with PlatformIO (but it does not build in arduino). Set serial monitor speed
    [PlantWateringESP8266.ino]
2019-11-16 Added KiCad project with the PCB
    [PlantWatering-B_Cu.gbr, PlantWatering-B_Mask.gbr, PlantWatering-B_Paste.gbr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]
2019-11-16 It can now connect and publish the soil moisture and voltage level via MQTT
2019-11-17 Go into AP mode if the TX and RX pins are shorted at boot
    [PlantWateringESP8266.ino]
2019-11-17 Added license for the PCB and details about where the licenses apply in the README
2019-11-20 Fixed bug, as we did not actually wait for the MQTT client to connect
    [PlantWateringESP8266.ino]
2019-11-22 Just restart if the SPIFFS fails to initialize
    [PlantWateringESP8266.ino]
2019-11-26 Only interrupt on the rising edge and use a flag to tell when the interrupt has occurred
2019-11-26 Fixed exception, as we can not call function that are not also in IRAM from inside an interrupt
    This seemed to only cause an exception on power on resets
    [PlantWateringESP8266.ino]
2019-11-27 Set the json_attributes_topic, so device state will automatically show up in Home Assistant
    Also send the software version as part of the state
2019-11-27 Fixed compatibility with Espressif 8266 2.3.0 platform
    This was triggered when the platform was updated from 2.2.3 -> 2.3.0
    See: https://github.com/esp8266/Arduino/commit/a389a995fb12459819e33970ec80695f1eaecc58
2019-11-29 Blink the LED when the board is updating
2019-11-29 Do not override the existing file system image on OTA
    See: https://github.com/esp8266/Arduino/pull/6505
2019-11-29 Updated guide on how to use the device with Home Assistant
2019-11-29 Only override the config topic if the value where actaully changed, fixed HTTP POST form response HTTP code and only reset the "override_retained_config_topic" variable if the message was actually pu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
    [PlantWateringESP8266.ino]
2020-01-20 Handle when the soil moisture timer overflow correctly
    This was caused due to the fact that it was a signed integer aka int
    [PlantFriends.ino]
2020-04-11 Added support for the BME280 temperature, pressure and humidity sensor
2020-04-18 Round the reported values and changed the temperature icon
2020-05-01 Added calibration routine for soil moisture sensor
2020-05-01 Added png images of schematic and PCB
2020-05-01 Created html pages for the calibration steps
2020-05-01 Fixed bug in soil moisture measurement that would cause absurdly high readings. Added sorting and median, changed calibration html responses to use sites
    [PlantFriends.ino]
2020-05-01 Tried to add watering threshold in pct, didn't seem to work
    [PlantFriends.ino]
2020-05-02 Calculating state of charge of battery
2020-05-03 Fixes from code review
    [PlantFriends.ino]
2020-05-03 Updated README.md with calibration guide and images
2020-05-03 Always watering at full throttle
2020-05-03 Fixed review comments I had missed before
    [PlantFriends.ino]
2020-05-20 Added enclosure files
    [Plant_Friends_Enclosure_bottom.step, Plant_Friends_Enclosure_bottom.stl, Plant_Friends_Enclosure_top.step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]
